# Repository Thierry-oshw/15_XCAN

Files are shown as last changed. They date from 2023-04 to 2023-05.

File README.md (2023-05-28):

# Can controller and CAN transceiver module

Can module to easily add CAN support to anything with SPI

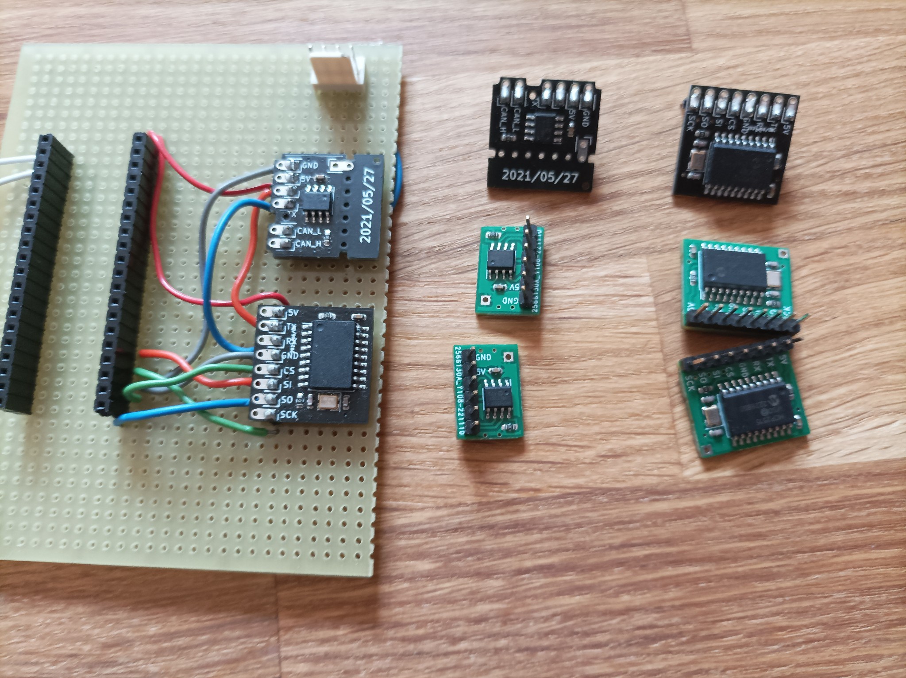
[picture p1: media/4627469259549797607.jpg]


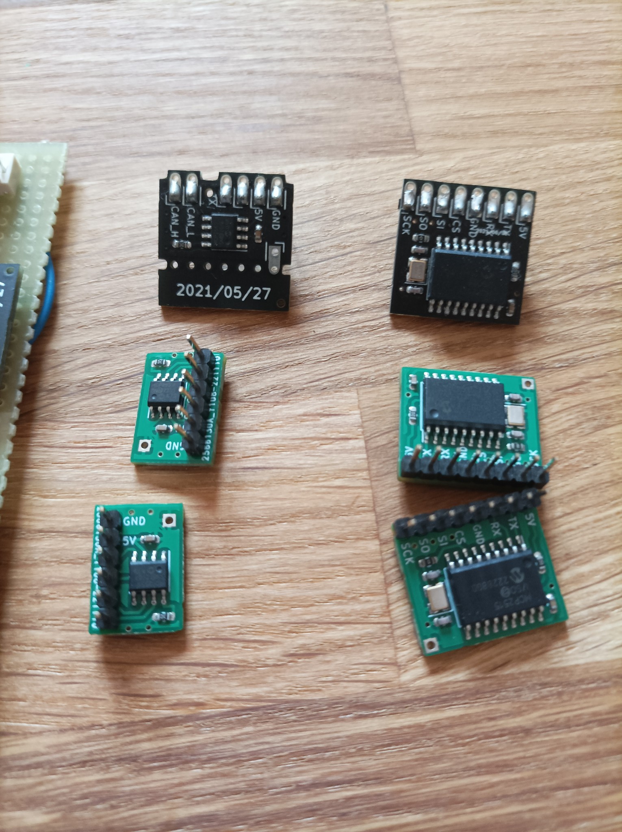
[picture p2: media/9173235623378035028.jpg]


[Link for controller](https://github.com/Thierry-oshw/17_CAN_Controller)

[Link for transceiver](https://github.com/Thierry-oshw/15_XCAN)

## Features
- Small (Controller is 18x20 mm, Transceiver is 17x15 mm)
- Cheap (2 layer and components on one side)
- 2.54 header + castellated pad for direct board to board soldering

## Made with

- [Kicad V6](https://www.kicad.org/)

## Schematic

### 15 XCAN Schematic

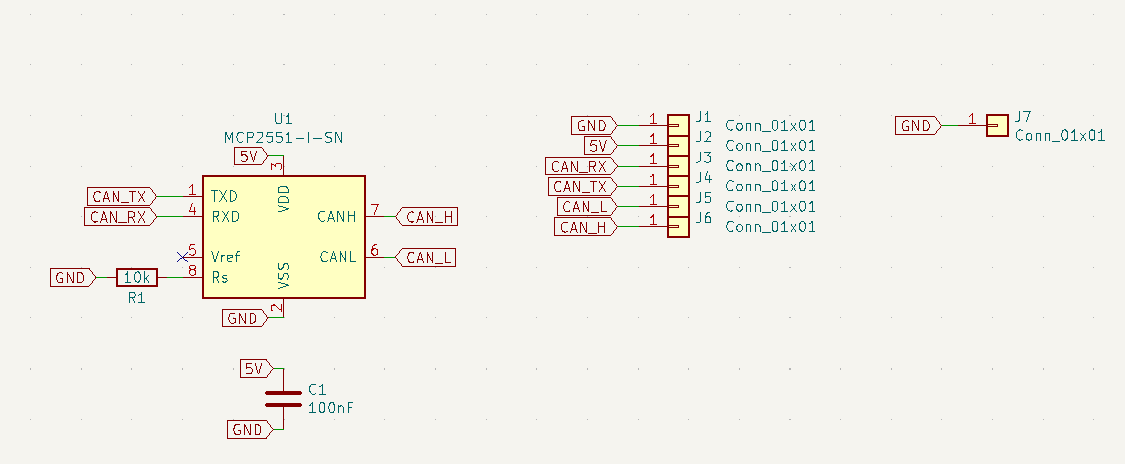
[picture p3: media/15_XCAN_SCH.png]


### 17 CAN Controller Schematic

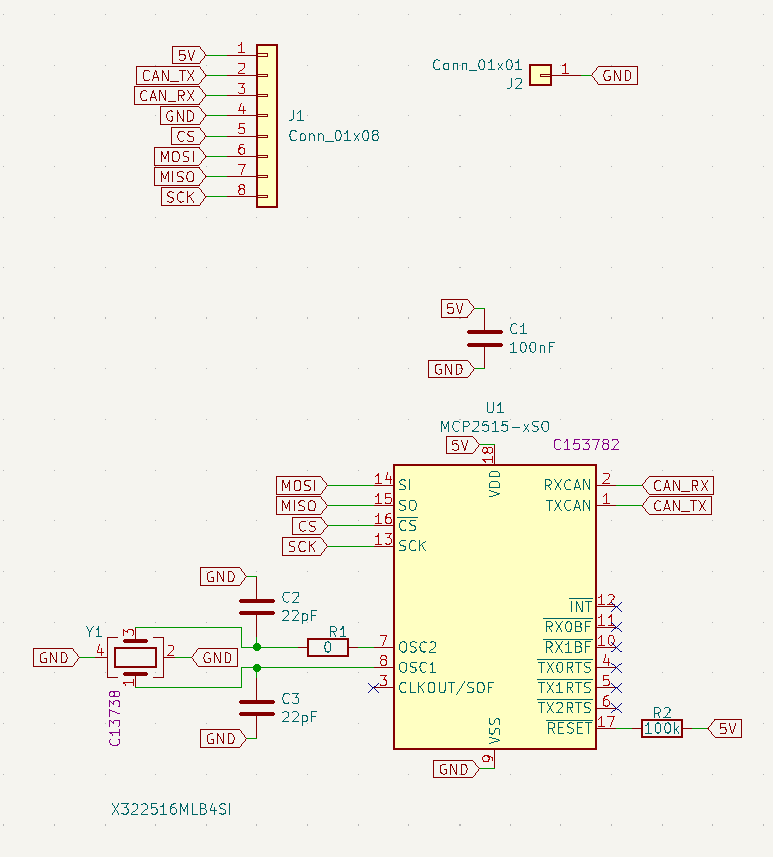
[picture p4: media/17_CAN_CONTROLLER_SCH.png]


## Build the PCB

PCB has been fully tested on multiple projects

[CAN Controller build files](https://github.com/Thierry-oshw/17_CAN_Controller/tree/main/fabrication_2023_04_23)

[CAN Transceiver build files without castellated holes](https://github.com/Thierry-oshw/15_XCAN/tree/main/fabrication_2023_04_21)

[CAN Transceiver build files with castellated holes](https://github.com/Thierry-oshw/15_XCAN/tree/main/fabrication_2023_04_21_CH)

## Authors

- Thierry Orlandi ([Hardware Freelance](https://www.linkedin.com/in/thierry-orlandi))
- Yohann Belair ([R&D Freelance](https://github.com/ciborg971))

## License
[CERN Open Hardware Licence Version 2](https://github.com/Thierry-oshw/15_XCAN/blob/main/LICENSE.txt)

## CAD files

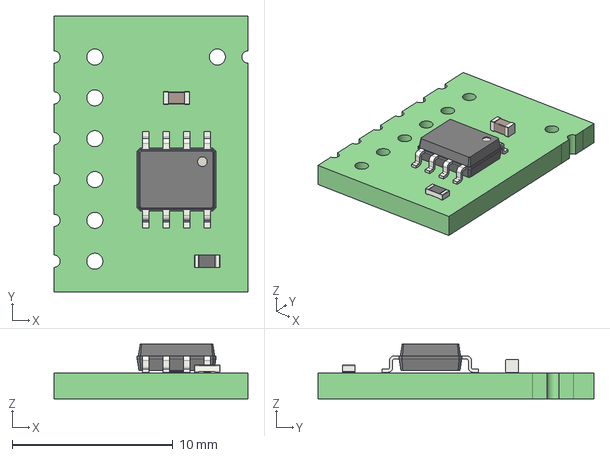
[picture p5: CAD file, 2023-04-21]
15_XCAN.step
12.1 x 17.1 x 3.40 mm
15_XCAN PCB

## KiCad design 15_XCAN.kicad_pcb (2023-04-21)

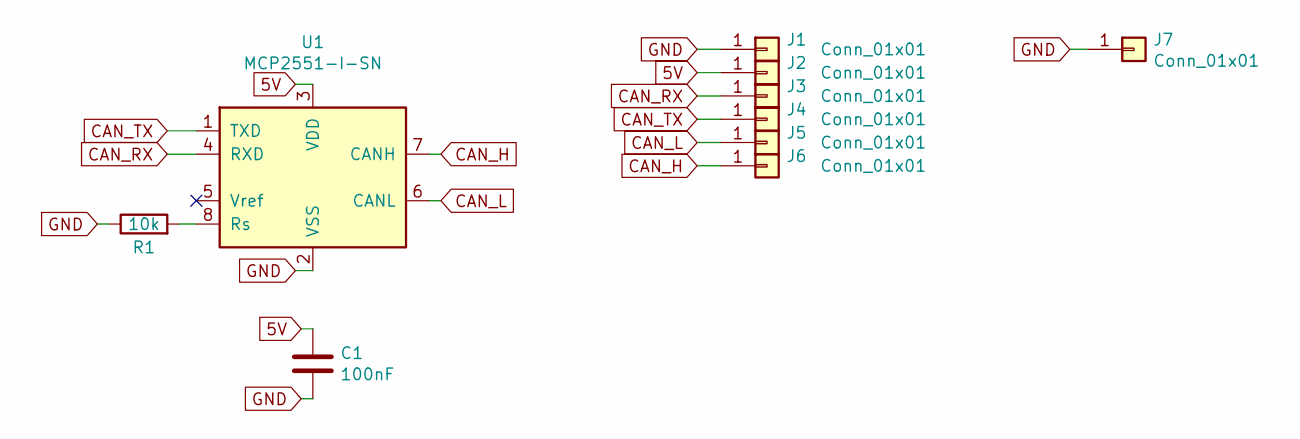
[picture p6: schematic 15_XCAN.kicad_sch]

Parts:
C1: 100nF; C_0603_1608Metric; LCSC C14663
J1, J2, J3, J4, J5, J6: Conn_01x01; Castellated_conn
J7: Conn_01x01; Cast_co_1_905
R1: 10k; R_0603_1608Metric_Pad1.05x0.95mm_HandSolder; LCSC C25804
U1: MCP2551-I-SN; SOIC-8_3.9x4.9mm_P1.27mm; LCSC C49558

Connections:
5V: C1.1, J2.1, U1.3 (VDD)
CAN_H: J6.1, U1.7 (CANH)
CAN_L: J5.1, U1.6 (CANL)
CAN_RX: J3.1, U1.4 (RXD)
CAN_TX: J4.1, U1.1 (TXD)
GND: C1.2, J1.1, J7.1, R1.1, U1.2 (VSS)
unnamed: R1.2, U1.8 (Rs)

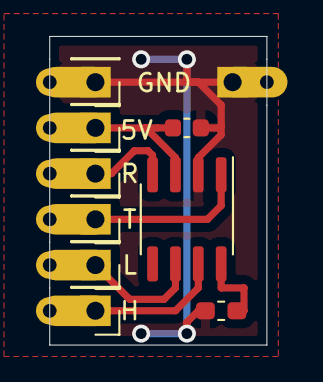
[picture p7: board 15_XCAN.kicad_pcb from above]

Board: 2 copper layers, 12.1 x 17.1 mm, 10 parts (1 on the bottom side), 7 nets.

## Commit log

2021-05-27 creation
    schema + routage
    [15_XCAN-B_Cu.gbr, 15_XCAN-B_Fab.gbr, 15_XCAN-B_Mask.gbr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]
2021-07-26 maj split librairies
    [15_XCAN.kicad_pcb, 15_XCAN.sch]
2022-10-30 maj kicad v6
    [15_XCAN.kicad_pcb, 15_XCAN.kicad_sch]
2022-10-31 correction chemin model 3D
    [15_XCAN.kicad_pcb, 15_XCAN.step]
2022-11-02 réduction de taille du pcb
    [15_XCAN.kicad_pcb, 15_XCAN.kicad_sch, 15_XCAN.step]
2022-11-02 maj step
    passage de wrl à step
    suppression de fichier.pro
    [15_XCAN.kicad_pcb, 15_XCAN.step]
2022-11-07 maj fichiers de fabrication
    [15_XCAN-B_Cu.gbl, 15_XCAN-B_Cu.gbr, 15_XCAN-B_Fab.gbr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]
2023-04-21 maj
    ajout sur silk
    changement sourcing jlcpcb
    [15_XCAN-B_Cu.gbl, 15_XCAN-B_Fab.gbr, 15_XCAN-B_Mask.gbs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]
2023-04-21 version castellated holes
    rajout des castellated holes
    [15_XCAN-B_Cu.gbl, 15_XCAN-B_Fab.gbr, 15_XCAN-B_Mask.gbs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]
